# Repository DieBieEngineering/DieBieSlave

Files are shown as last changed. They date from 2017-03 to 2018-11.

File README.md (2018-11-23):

DieBieSlave - Hardware
===
# Introduction
During my work at the University of Twente at the faculty of Biomechanical Engineering I gained interest in EtherCAT and its applications. I learned that many of the projects at this faculty (and other faculties in the field of robotics) desire a custom coupling between a unique sensor and EtherCAT, a coupling that is not always easy to realise with the existing slaves. During my work I helped designing an EtherCAT slave based on the ET1100, this ASIC comes in a BGA package, needs two external ethernet phy's and lots of passive components. The ET1100 is more than capable of coupling all desired applications to EtherCAT however in some applications it's to cumbersome to implement knowing that the LAN9252 can do almost the same and has the ASIC + 2 Phy's intergrated in one QFN package. 

Knowing about the existence of the LAN9252 and hearing the need for a "sensor <--> EtherCAT" interface motivated me to design the project presented here; the DieBieSlave, a universal EtherCAT slave that is able to couple 'any' I2C, SPI, UART, analog, digital or CAN based sensor to EtherCAT. The idea is that the DieBieSlave is universal for any sensor application and has all the 'complex' EtherCAT, power supply and microcontroller hardware on one PCB whilst the only thing that differs per sensor implementation is a cheap and simple daughter board. Every sensor of course needs its unique code to initialise and sample the sensor. 

The DieBieSlave looks like this:
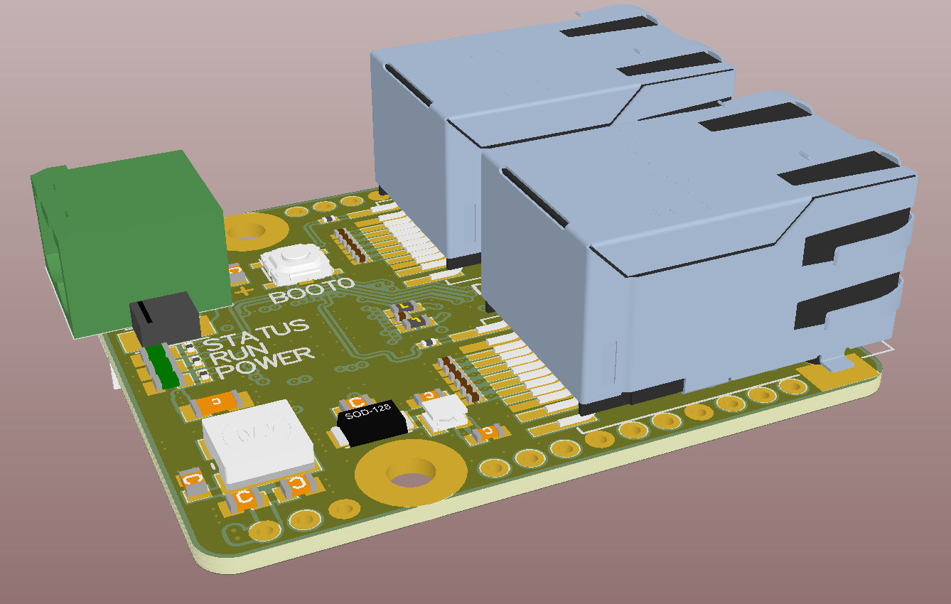
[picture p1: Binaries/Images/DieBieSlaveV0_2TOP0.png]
DieBieSlave V0.2 TopView

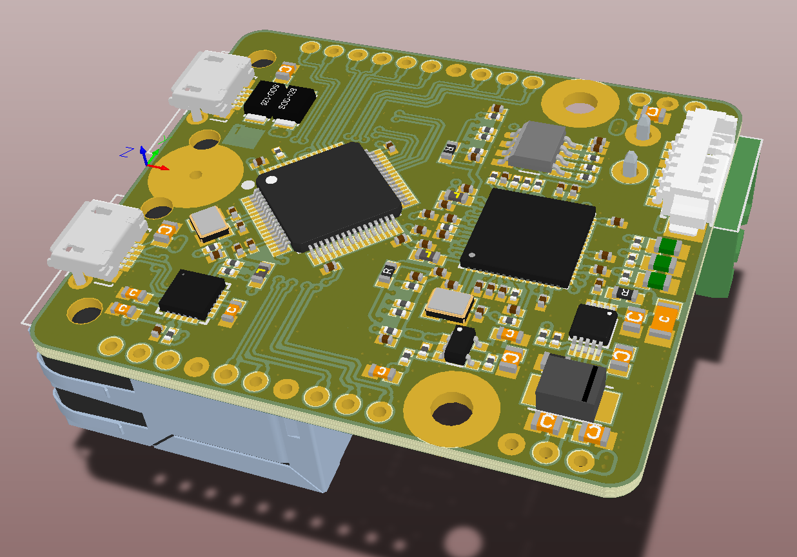
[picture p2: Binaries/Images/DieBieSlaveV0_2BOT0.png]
DieBieSlave V0.2 TopView

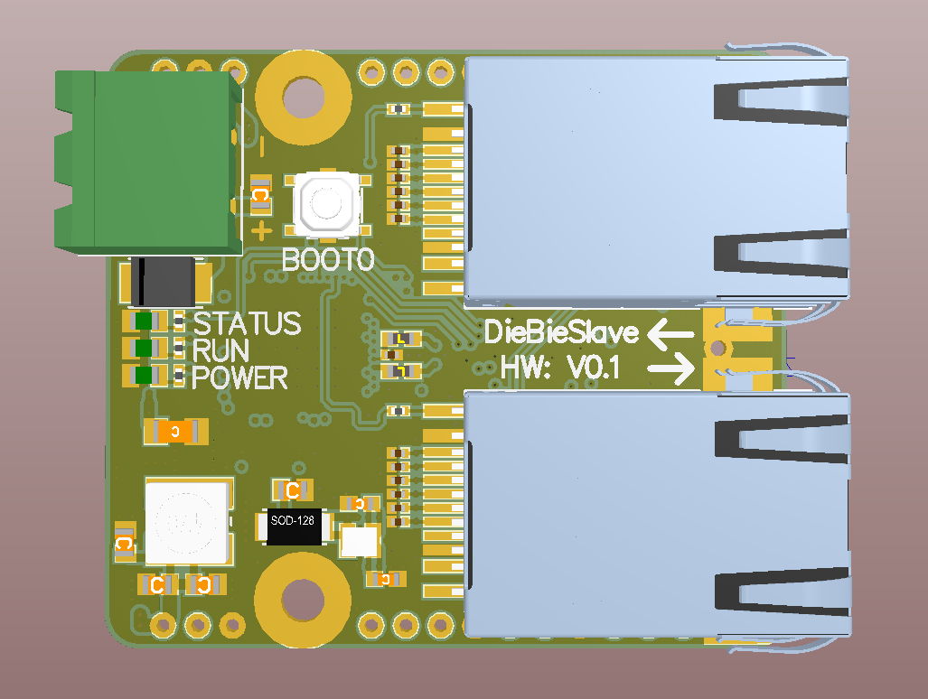
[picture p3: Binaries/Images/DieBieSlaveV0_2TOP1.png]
DieBieSlave V0.2 TopView

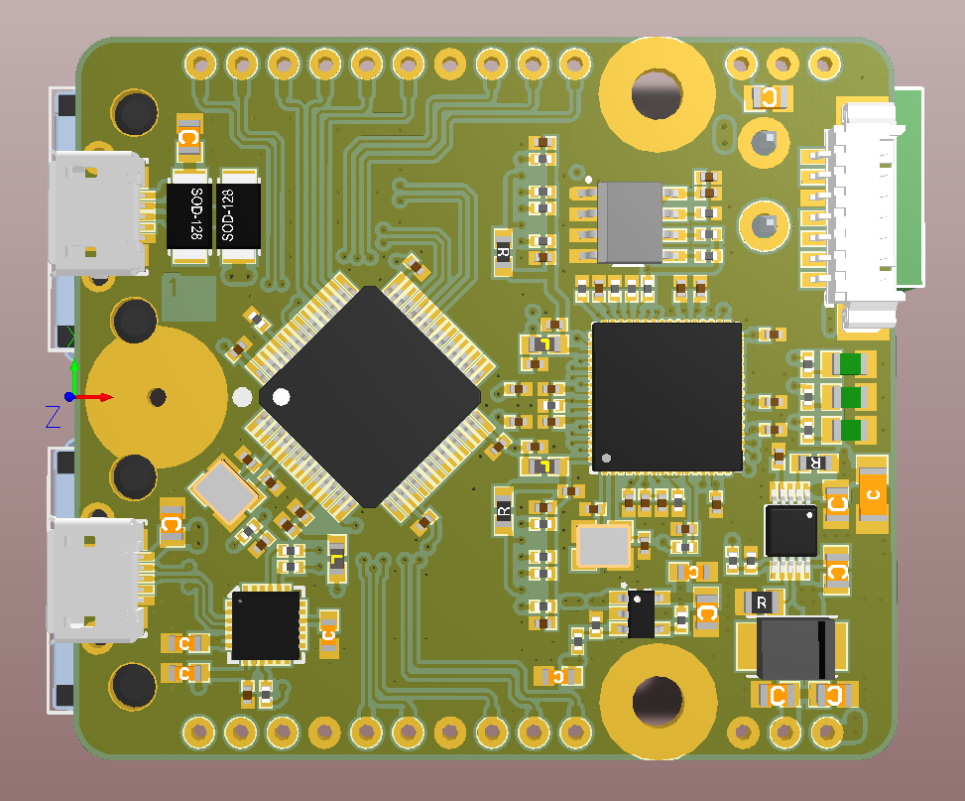
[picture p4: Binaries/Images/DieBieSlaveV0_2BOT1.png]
DieBieSlave V0.2 TopView


On the topside you can see:
* DC (10-30V) power input jack.
* EtherCAT input/output connectors 
* EtherCAT, power and software status LEDs
* BOOT0 HW serial bootloader enable button

On the bottom:
* Micro USB connector that is connected to the HW serial UART1 for general serial communication and HW Bootloader
* Micro USB connector that is connected to the HW USB peripheral of the STM32F303RET6
* 7Pin picoblade debug connector that is connected to the SWD and UART2 peripheral of the STM32F303RET6.

Both sides:
The holes on both edges of the DieBieSlave interface to all exposed (I2C, SPI, UART, analog, digital and CAN) peripherals on the STM32F303RET6 and should be connected to the desired target sensor. Standard 2.54mm headers can be soldered to both sides of the DieBieSlave allowing the use of standard 2.54mm male/female headers to connect standaard prototype board to either the small area on top or the full area on the bottom (realising either a compact or extensive interface). The board connected to the pin on te side that interfaces to a sensor is called a daughter board.

More details can be found in the schematic [here](/Project%20Outputs%20for%20DB10012_UniversalSlave/DB10012_DieBieSlave.PDF).

### Latest hardware release (production files)

* V0.1 Initial hardware
   This version has the following bug:
   * The INT pint of the LAN9252 was incorrectly connected to PC5 (cannot be muxed to INT input when I2C INT input also used) but should have been connected to PB0 (allows INT functionality at all times). This bug is fixxed in V0.2.
   
* V0.2 Fixed version of V0.1 with added functionality (current version)
   This version has some added functionality:
   * The DC-DC power input 10-30V is also routed to the header pins, now the DieBieSlave can be powered by the daughter board if desired.
   
Production data for most recent version can be found [here](Project%20Outputs%20for%20DB10012_UniversalSlave). And the schematic in PDF [here](DB10012_UniversalSlave.PDF).

### Features
The DieBieSlave is designed in such a way that it is easy to manufacture and has a relatively small footprint (by a professional). The implementation of a daughter board is completely up to the user. The DieBieSlave PCB has the following features:

* Power LED on both sides of the PCB.
* EtherCAT RUN LED on both sides of the PCB.
* Sofware status LED on both sides of the PCB connected to pin PB15.
* DC input range of 10-30V (possibly broader but untested) allowing simple implementation in 12V and 24V systems.
* Onboard +5V and +3V3 SMPS power supplies that are exposed to the daughter board header.
* Large powerful microcontroller with DSP and FPU STM32F303RET6 (cortex-M4 512Kbytes flash and 64Kbyte SRAM).
* RJ45 EtherCAT in and output connectors.
* LAN9252 QFN based EtherCAT ASIC.

### Electrical specifications
* DC input power range 10-30V reverse polarisation protected
* The +5V power supply can deliver up to 400mA
* The +3V3 power supply  can deliver up to 200mA

# Realisation
As stated in the introduction the DieBieSlave is a universal EtherCAT slave implementation that will always need a daughter board supplying the DieBieSlave with information that should be put on the BUS. An example DieBieSlave and daughter board implementation is given here:
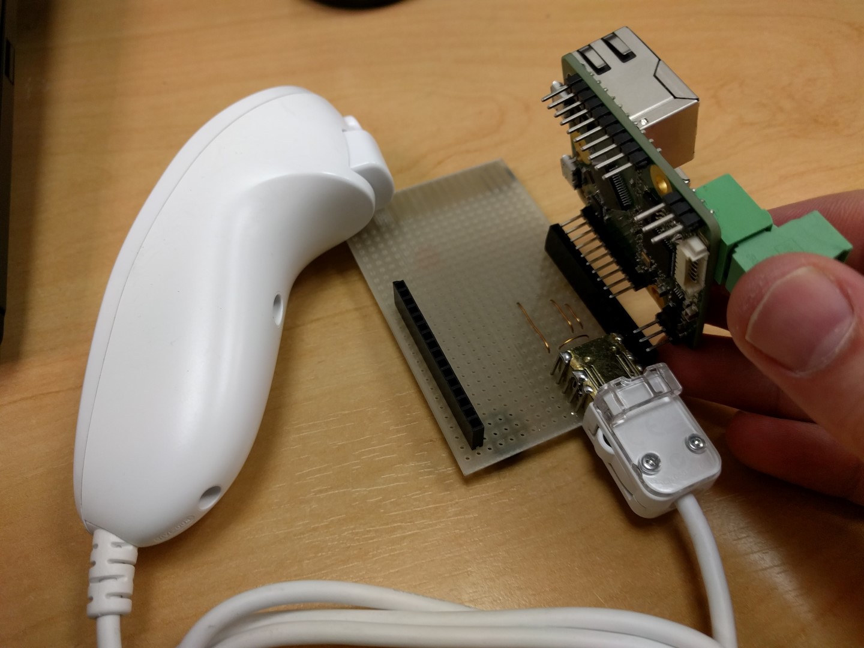
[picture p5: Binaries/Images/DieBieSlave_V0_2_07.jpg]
Daughter board and DieBieSlave separated

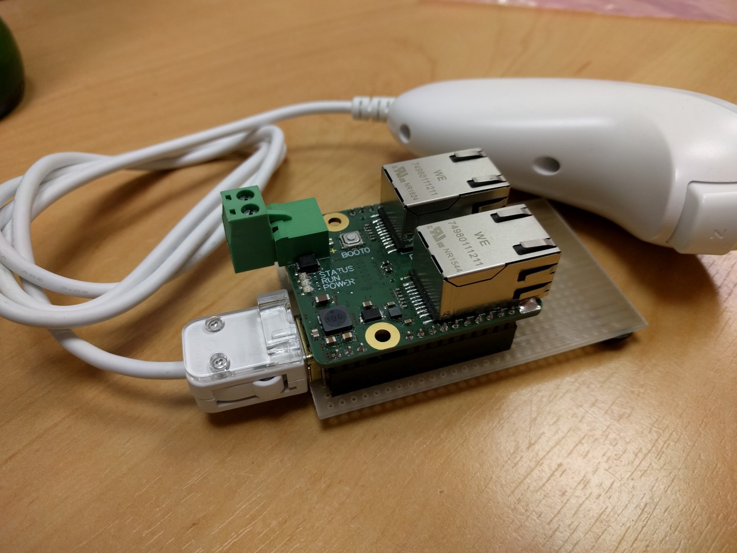
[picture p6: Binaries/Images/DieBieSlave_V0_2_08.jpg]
Daughter board and DieBieSlave connected

As seen the daughter board can be anything from standard perforated prototype board up to a custom designed board carrying the sensor. 

#### LAN9252 vs ET1100
Altrough the LAN9252 seems a perfect replacement for the ET1100 with its two embedded phy's, the QFN package and its low amount of external components it has a big drawback on the software side. Whilst the ET1100 has a transparant interface to its internal RAM over SPI the LAN9252 has not and needs some form of adres translation that prevents large chunks of (PDO) data to be written in a single block, this prevents the use of DMA syncing between uC and LAN9252. The only alternative is rather software labour intensive (the adres translation needs to be done in software) compared to its DMA alternative. This is no deal breaker for sensor acquisition (sensors need very little processor power) but will be a drawback in realtime systems like motor controllers.

#### Used technology
The IC's used with their corresponding functionality:
* STM32F303RET6 -> Main microcontroller.
* LAN9252/ML -> EtherCAT slave controller with build-in phy's.
* M24C16-WMN6P -> EEPROM for LAN9252
* LM25011MY/NOPB -> DC power input to +5V converter.
* LMR10510XMFE/NOPB -> +5V to +3V3 converter.
* 74980111211 -> RJ45 connectors with integrated magnetics.
* CP2104-F03-GM -> USB serial converter for bootloader and general serial communication.

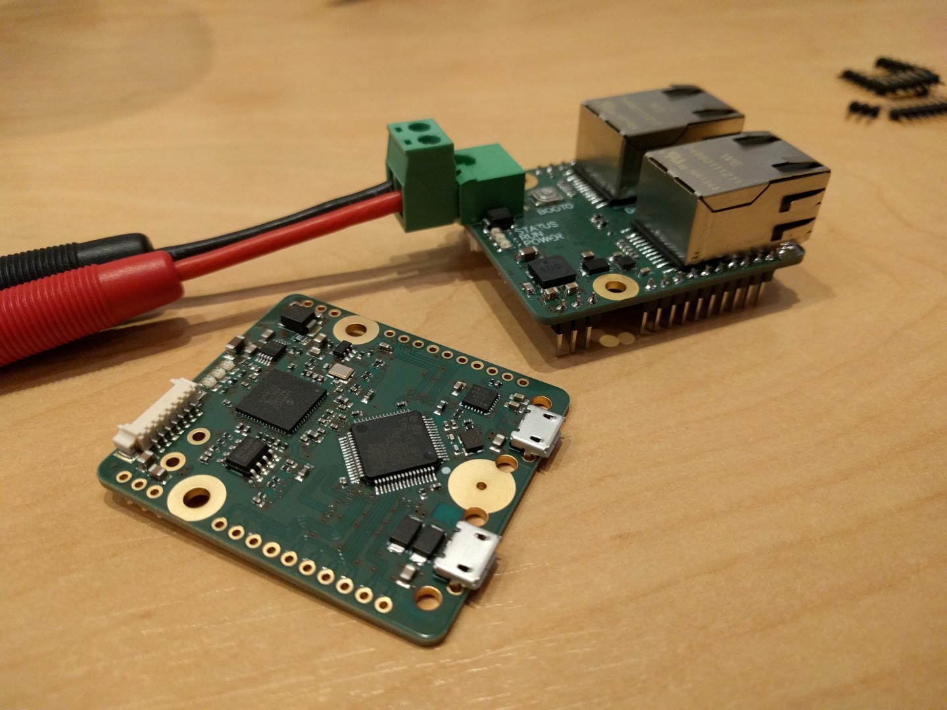
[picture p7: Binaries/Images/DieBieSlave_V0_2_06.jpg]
DieBieSlave V0.2 Dual PCB picture

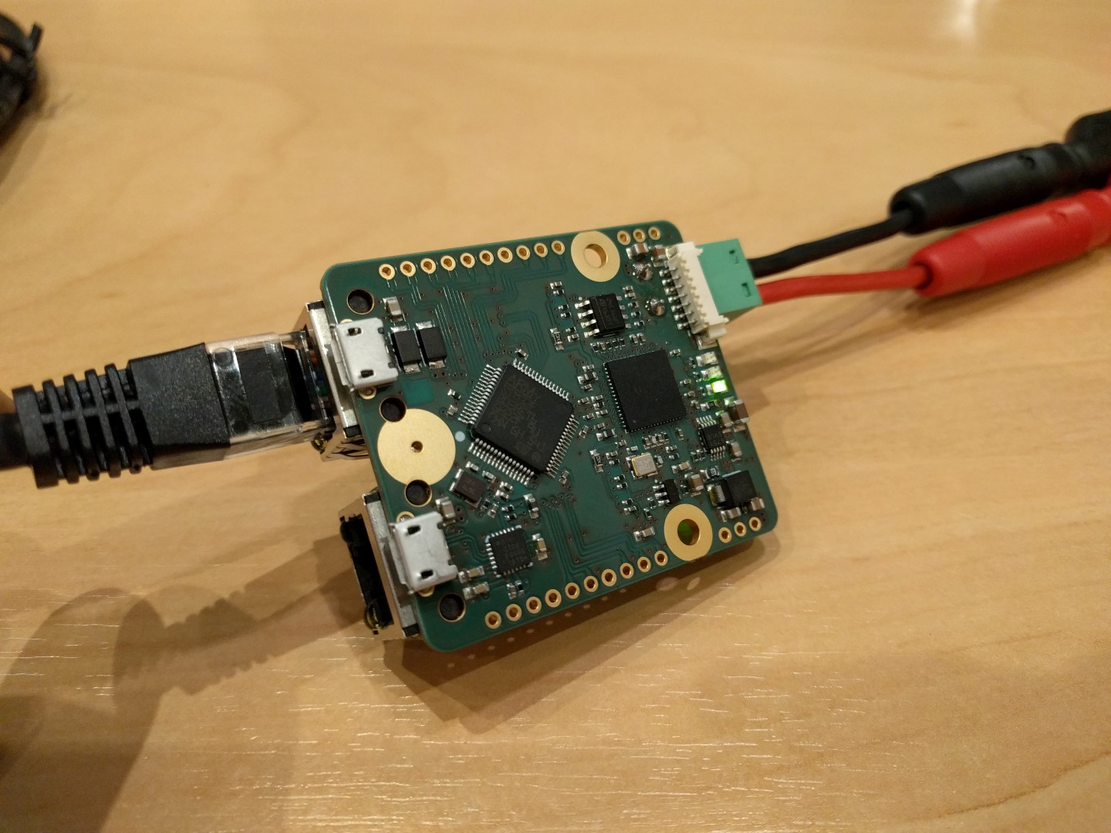
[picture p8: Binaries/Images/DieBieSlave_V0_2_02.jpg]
DieBieSlave V0.2 Bottom overview

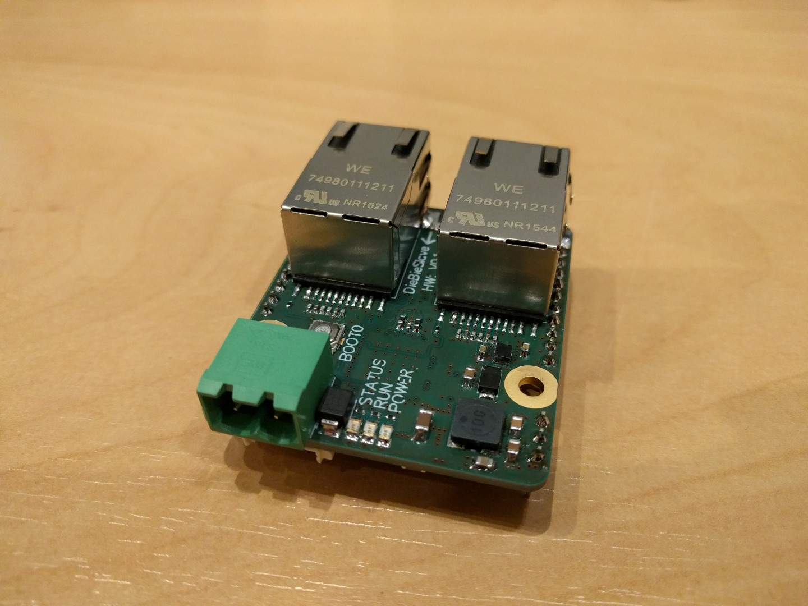
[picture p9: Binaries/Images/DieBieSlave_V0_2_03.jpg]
DieBieSlave V0.2 Top overview

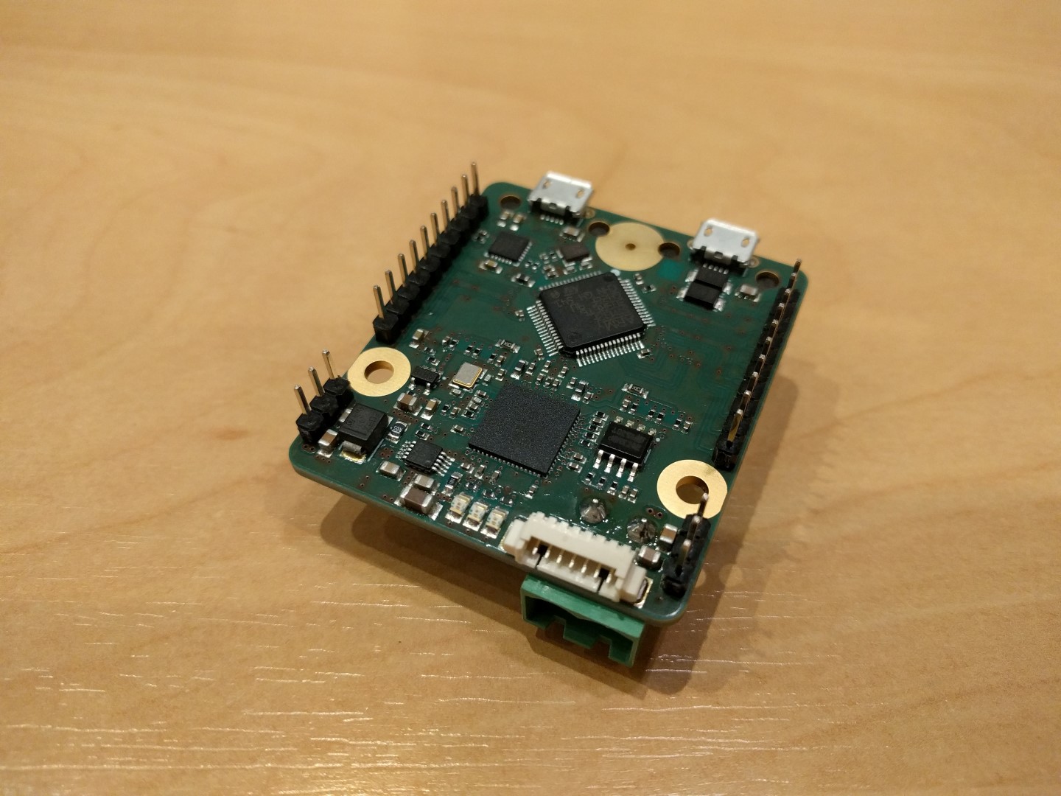
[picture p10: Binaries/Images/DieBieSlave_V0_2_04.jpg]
DieBieSlave V0.2 Bottom component overview

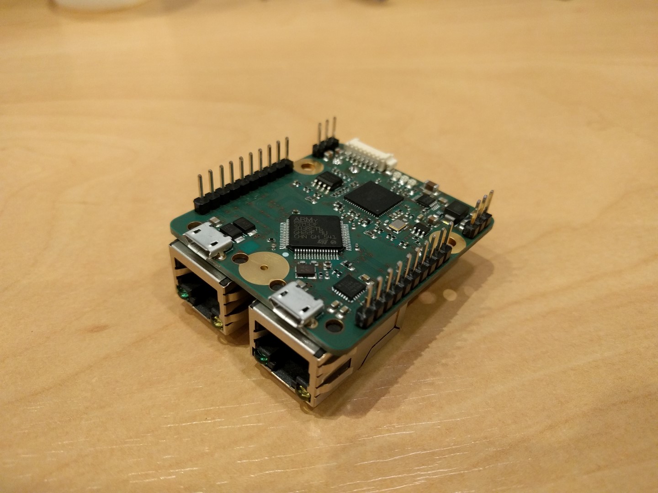
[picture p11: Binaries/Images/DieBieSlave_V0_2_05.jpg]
DieBieSlave V0.2 Bottom component overview


# Example usage
#### MPU9250/NunChuck to EtherCAT
Interfacing a Nun-chuck controller and MPU9250 sensors with EtherCAT:

VIDEO01 (http://www.youtube.com/watch?v=i7gFqLQb0EA)

#### More pictures
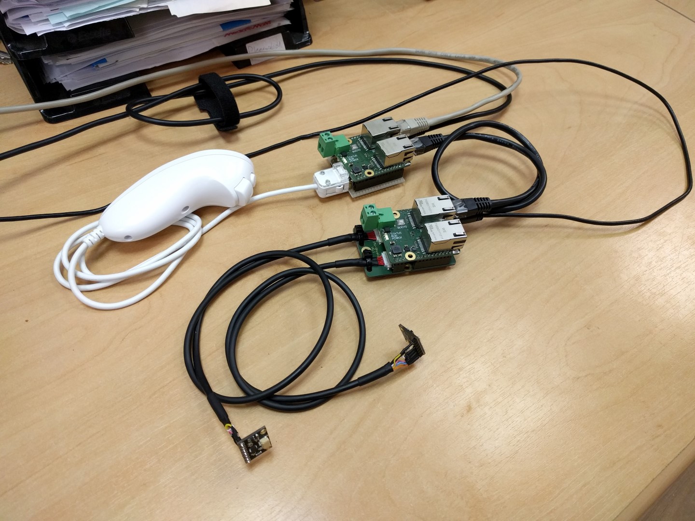
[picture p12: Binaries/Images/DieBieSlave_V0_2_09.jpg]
NunChuck slave and dual MPU9250 slave

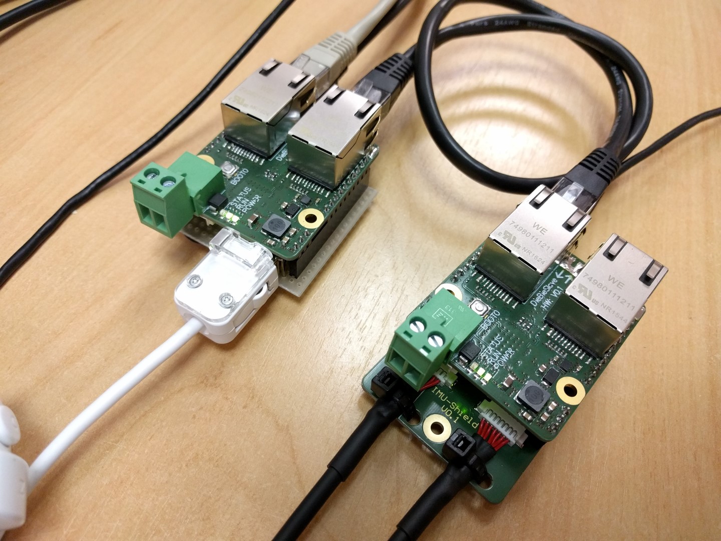
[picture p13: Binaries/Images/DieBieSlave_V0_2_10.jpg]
NunChuck slave and dual MPU9250 slave

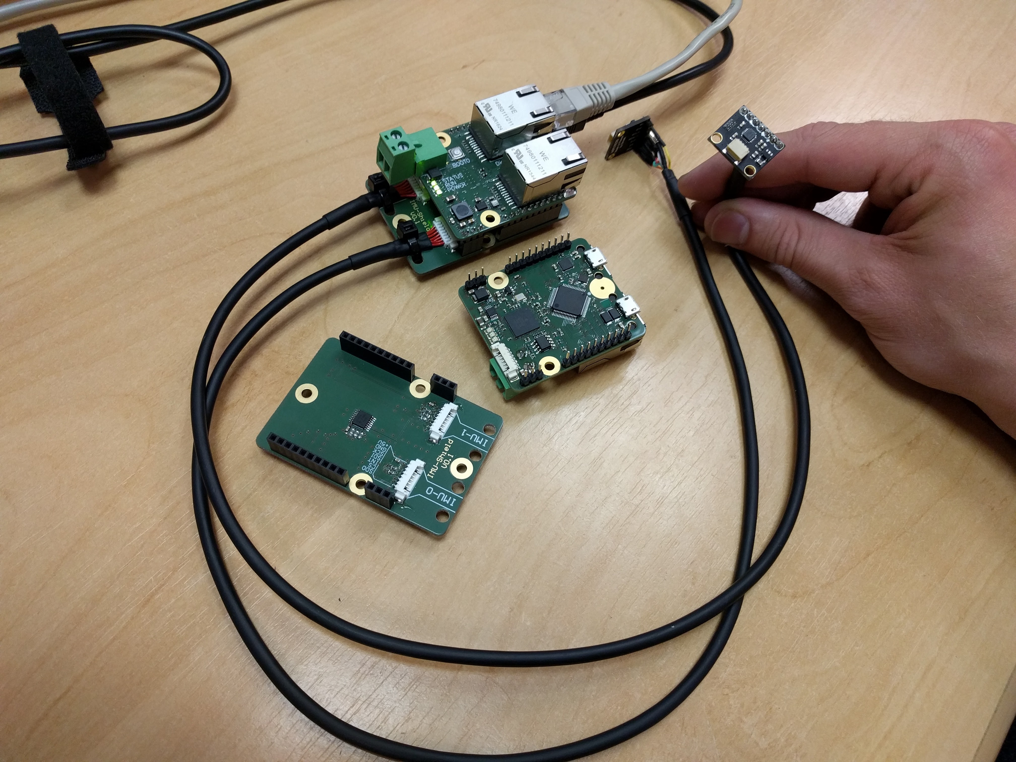
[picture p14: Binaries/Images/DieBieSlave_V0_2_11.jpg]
View of a Shield example

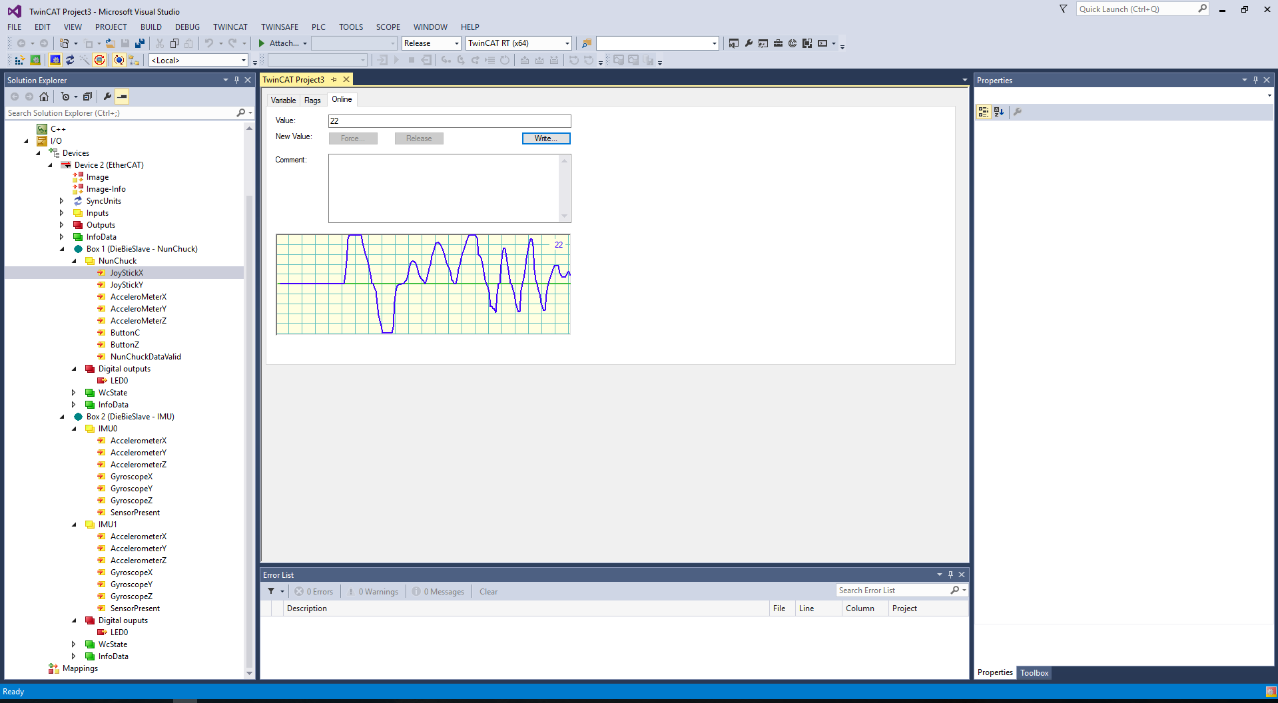
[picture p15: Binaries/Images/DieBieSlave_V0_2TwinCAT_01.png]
TwinCAT screenshot of both slave examples connected

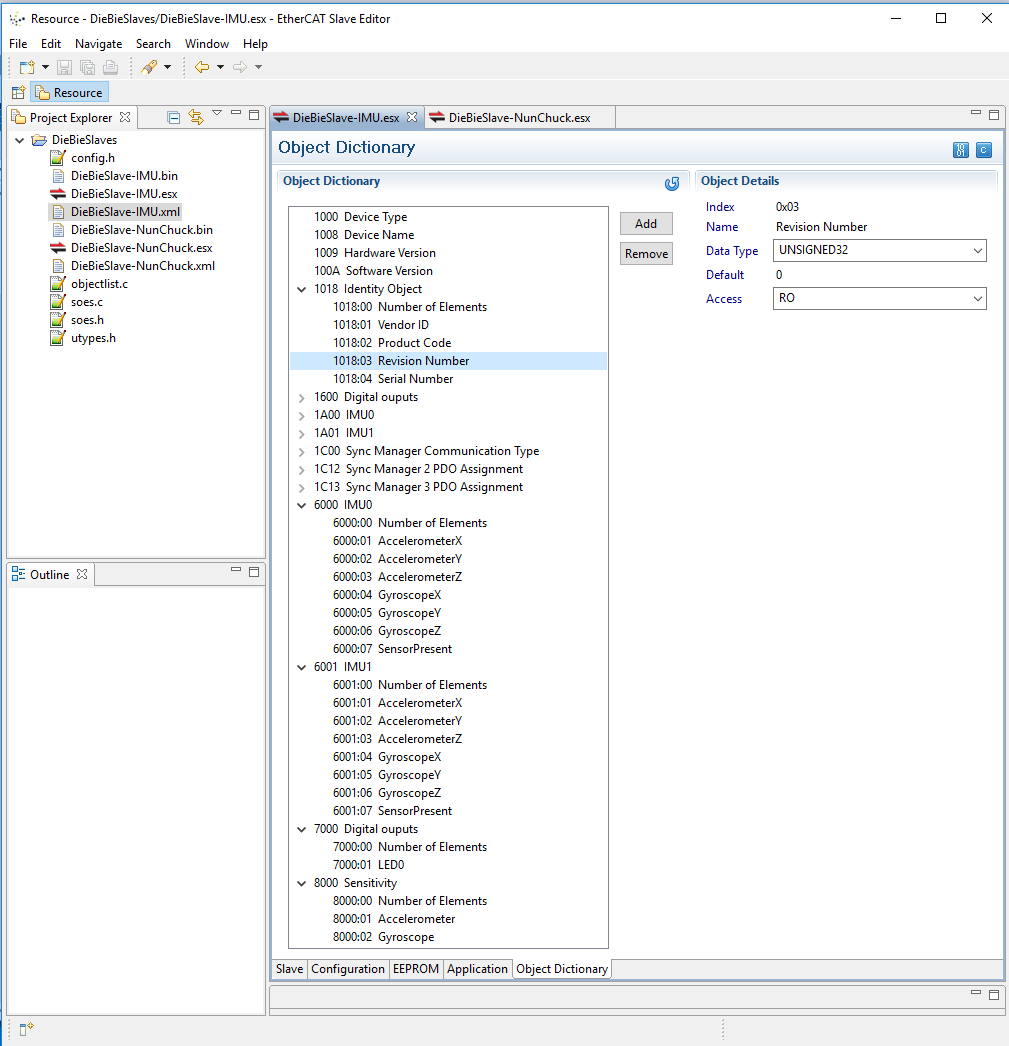
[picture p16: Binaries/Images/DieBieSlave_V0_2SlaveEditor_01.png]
Slave editor view of the SOES configuration


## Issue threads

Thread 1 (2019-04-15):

BOM and layer count

thomasfla, 2019-04-15:
Hi, thanks for this board, I think it will be very usefully for many project!

I'm considering building a couple of boards..
Do you have a BOM ready for the non-Altium users?

Also, looking at the gerber, it looks like it's a 6 layers board. Is it right? Do we really need 6 layers for this project or do you think it's doable on 4 layer with similar ? (or even 2?)

Best,
T.

DieBieEngineering, 2019-04-15:
Hi Thomas!

Thanks for your interest in the project. You can see all data with the free
Altium viewer license. The production data should be available in the repo
as well, either in releases or in the project output folder.

With this small size I am afraid that 6 layer is your only option.

Thanks ,
Danny

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

Closed 2019-06-15.

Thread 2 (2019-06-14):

Code Source

khaledlim, 2019-06-14:
If you can share your code source.I'm studying on a similar project
Thank you

DieBieEngineering, 2019-06-14:
https://github.com/DieBieEngineering/DieBieMS-Firmware

khaledlim, 2019-06-14:
Thank you so much.
if i have any question can i ask you ?

On Fri, Jun 14, 2019 at 10:57 PM Danny Bokma <notifications@github.com>
wrote:

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

DieBieEngineering, 2019-06-14:
Of course!

khaledlim, 2019-06-15:
I worked a conception of  a card that contains :

-STM32f407VGT6 microcontroller.
-Ethercat Slave controller LAN9252 like you connected with SPI1 and an
EEPROM 2Mbit with I2C.
-USB 2.0 FS .
-USB 2.0 HS with external PHY USB3300
-Connector VGA.
-Connector SWD

And i'm disable to program it in Keil V5 , I already did the configuration
of pins in CubeMX.

And why and how should i use TwinCAT software

Thanks

On Sat, Jun 15, 2019 at 12:48 AM Danny Bokma <notifications@github.com>
wrote:

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

DieBieEngineering, 2019-06-15:
That almost looks like a computer, what are you trying to build?

You use Twincat as for example the master controller.

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

khaledlim, 2019-06-16:
I want to build a Card of interfacing of a 6 axis Robot for Control
Automatisation using EtherCAT Fieldbus.
Which programme and libraries should I use for communication SPI1 between
the microcontroller and the LAN9252 ?

On Sat, Jun 15, 2019 at 3:37 PM Danny Bokma <notifications@github.com>
wrote:

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

Closed 2019-06-14.

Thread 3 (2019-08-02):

Placement of the electronic components

FCam1, 2019-08-02:
Hi,
Thanks a lot for this design !
I am building a DieBieSlave board and I encounter difficulties to know the implantation of each components.
I tried with Altium and Cadence to extract the names (L8,C1...) but I can't isolate the layer "name" for each side, it seems the names are on the same layer.
For the instant I wrote the name of each components one by one on a photo of the board but is fastidious and source of errors.

How did you do for mounting your board? Do you have the implantation scheme?

DieBieEngineering, 2019-08-05:
You can download a free Altium viewer version which allows you to see the
board in Altium. This is probably the best and easiest solution.

On Fri, Aug 2, 2019, 11:04 Florenc Caminade <notifications@github.com>
wrote:

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

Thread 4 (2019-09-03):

LAN9252 configuration

FCam1, 2019-09-03:
Hi,
We have built a board and it seems to work ! For the moment I did some tests with the  [SOEM library](https://github.com/OpenEtherCATsociety/SOEM) and the device is recognized as a slave.

As I understand the LAN9252 have to be configured through ethercat, for that you give an [DieBieSlave-IMU.esx](https://github.com/DieBieEngineering/DieBieSlave-Firmware-IMU/tree/master/ESIEtherCAT) and it has to be opened with [ethercat-SDK](https://rt-labs.com/refman/ethercat-sdk/slaveeditor.php) in order to generate a binary. This binary can be sent to the LAN9252 with this [eepromtool](https://github.com/OpenEtherCATsociety/SOEM/tree/master/test/linux/eepromtool), for example. Am I right ?
Another point : I can't generate the binary file in ethercat-SDK with the free licence. Did you buy the licence?

Thanks

DieBieEngineering, 2019-09-03:
Dear Florenc,

Thanks for your email! Sounds good!

Yes I use twincat and the xml file to configure/write the eeprom data to
the slave. The xml and esc are made with the tool provided by rt-labs, back
then the tool was free and allowed for the generation of this section and
description. I am not up to speed with the current status and whether it is
still free.......

Op di 3 sep. 2019 om 10:33 schreef Florenc Caminade <
notifications@github.com>:

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

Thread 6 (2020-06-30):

Wrong routing on decoupling capacitors

SavKok, 2020-06-30:
Hello,

There are some routing faults on decoupling capacitors. The power line track should go first throught the capacitor and the to the VDD pin.

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

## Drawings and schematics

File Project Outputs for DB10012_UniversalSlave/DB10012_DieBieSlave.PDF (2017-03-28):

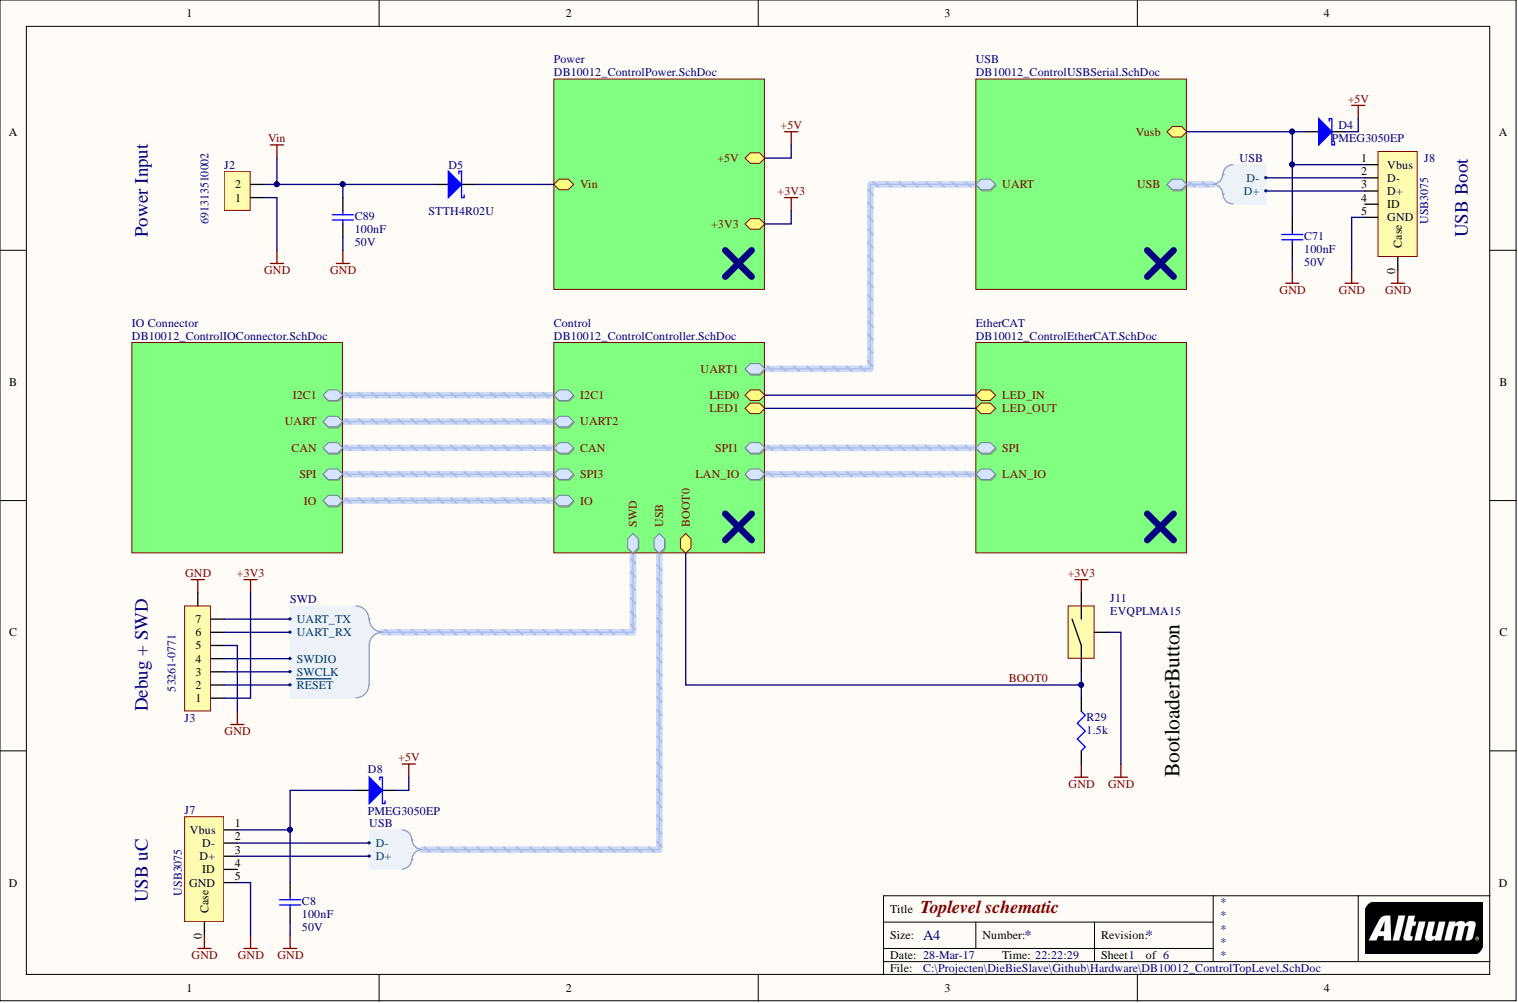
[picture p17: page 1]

Size: A | N umber: | Rev s
Date: 8-Mar-1 T ime: : | | Sheet f

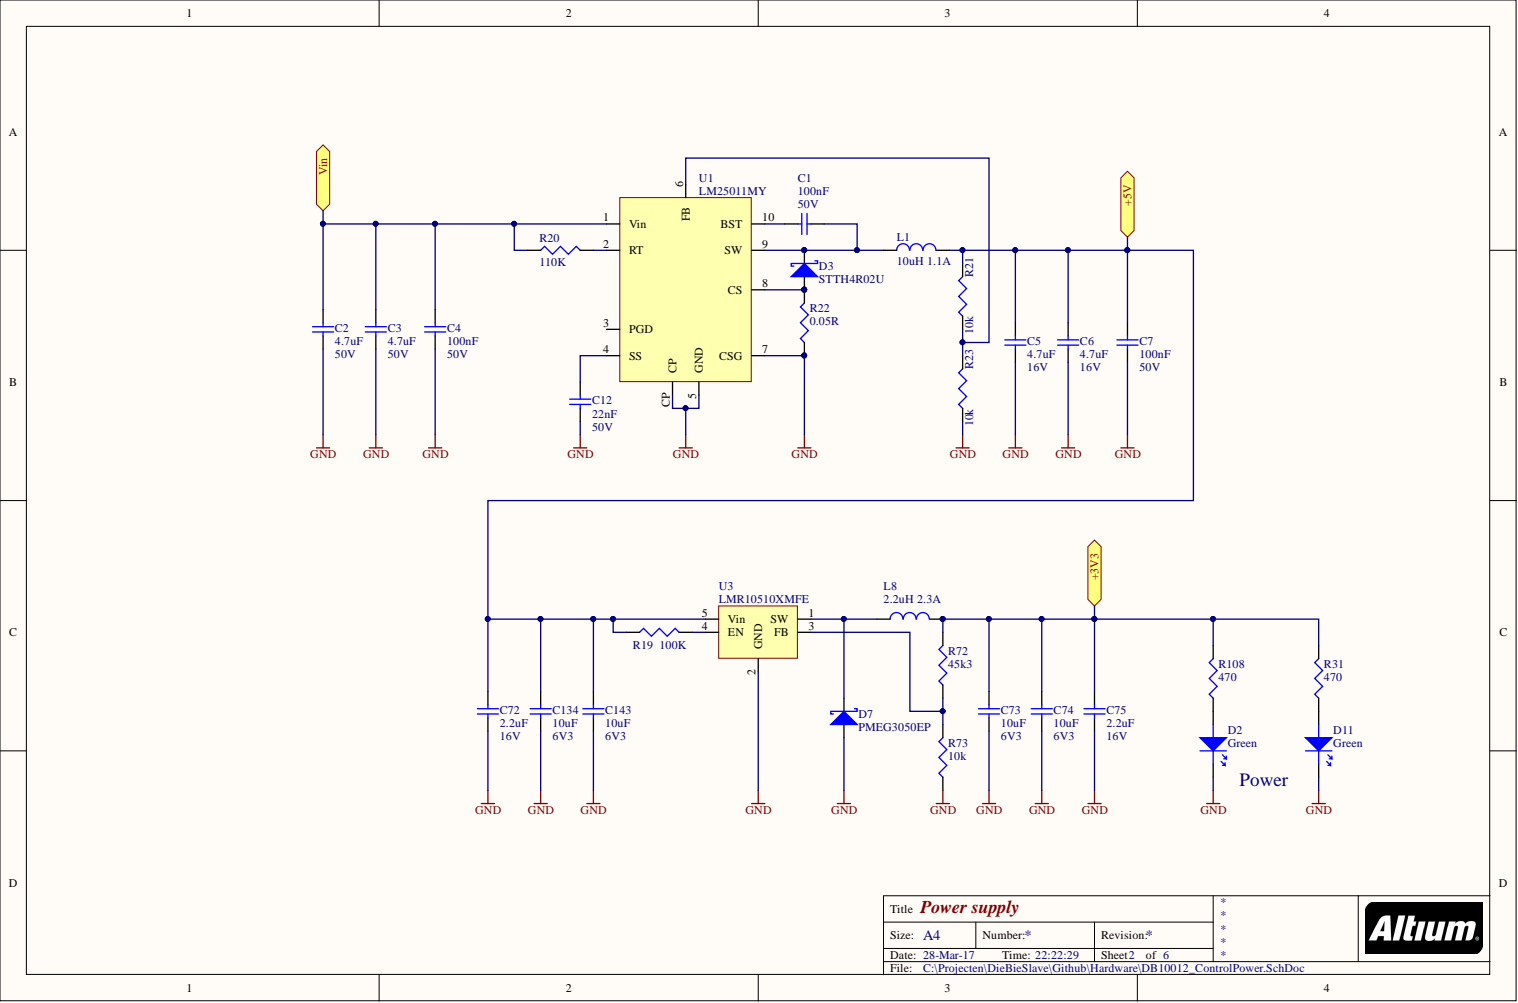
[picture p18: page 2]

Vin 1

Title Power supply | * *

Size: A4 | Number: * | Revision: *
28-Mar-17 Time: 22:22:29 | | Sheet of

C:\Projecten\DieBieSlave\Github\Hardware\DB10012_ControlPower.SchDoc

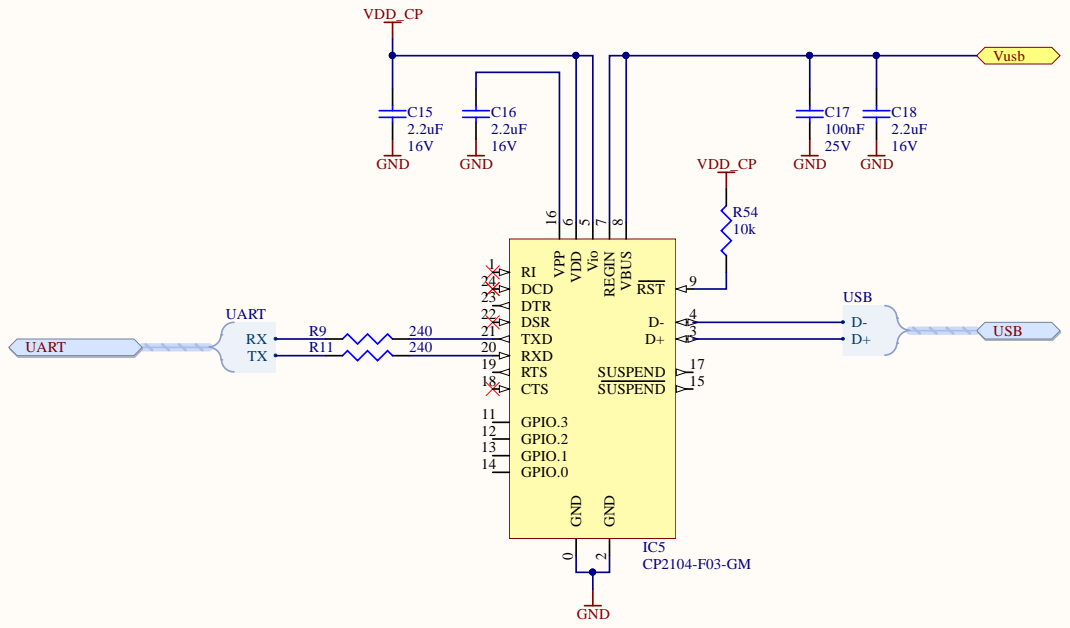
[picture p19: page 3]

C:\Projecten\DieBieSlave\Github\Hardware\DB10012_ControlUSBSerial.SchDoc

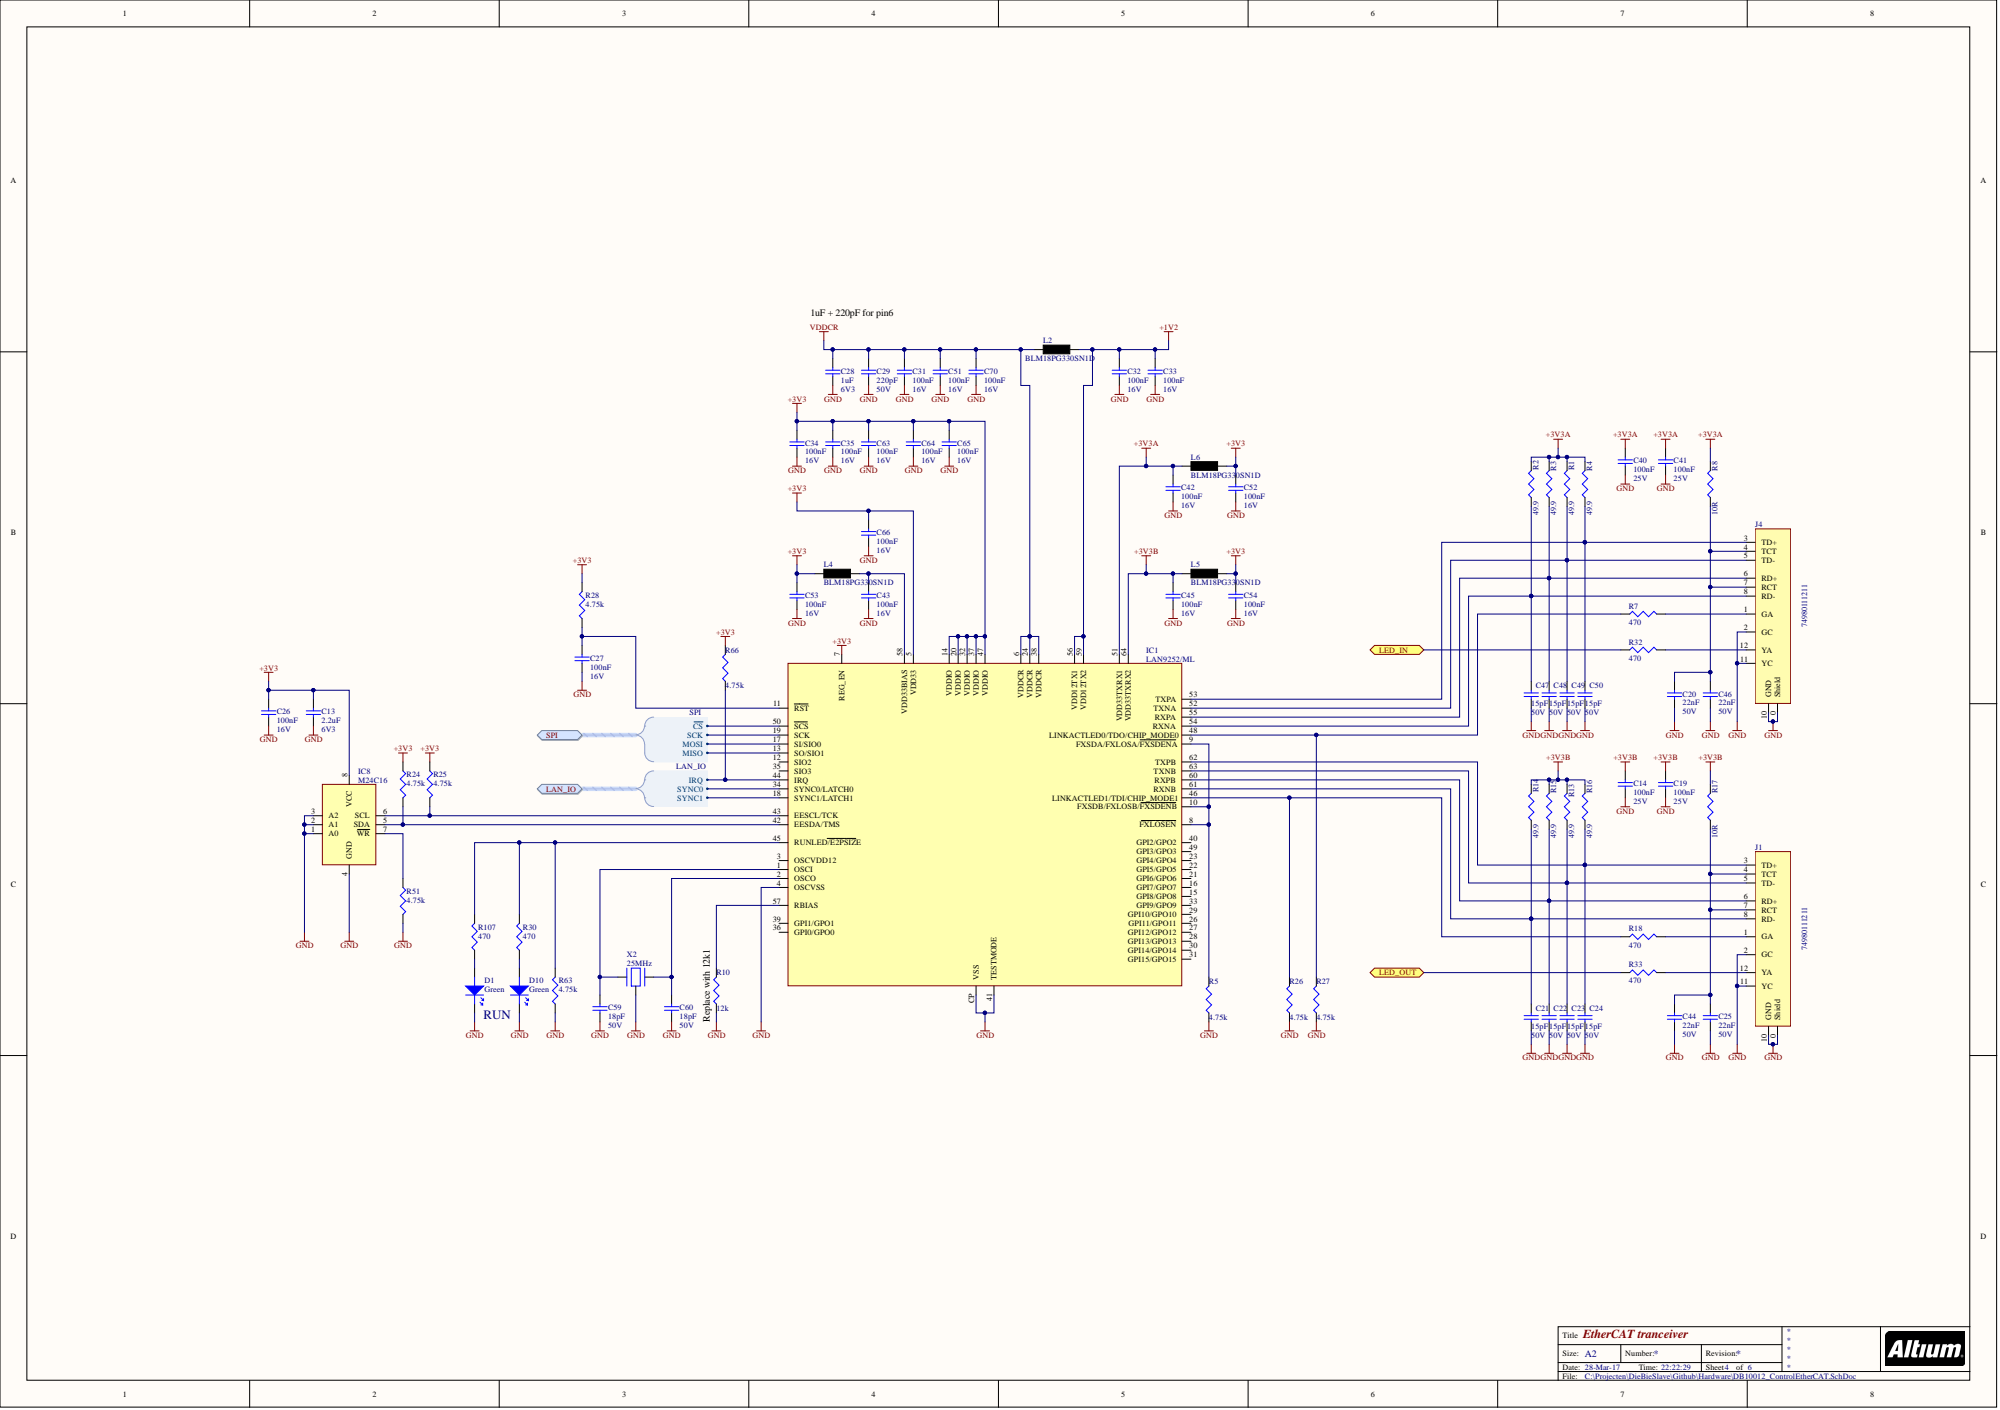
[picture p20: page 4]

6 0
6 1

4 6
1 0 | | G

2 | 5 | 4 2
1 | 7 | | 4 0 9 3 2

5 3 | | | | | 6
9 6 | | | | | 7

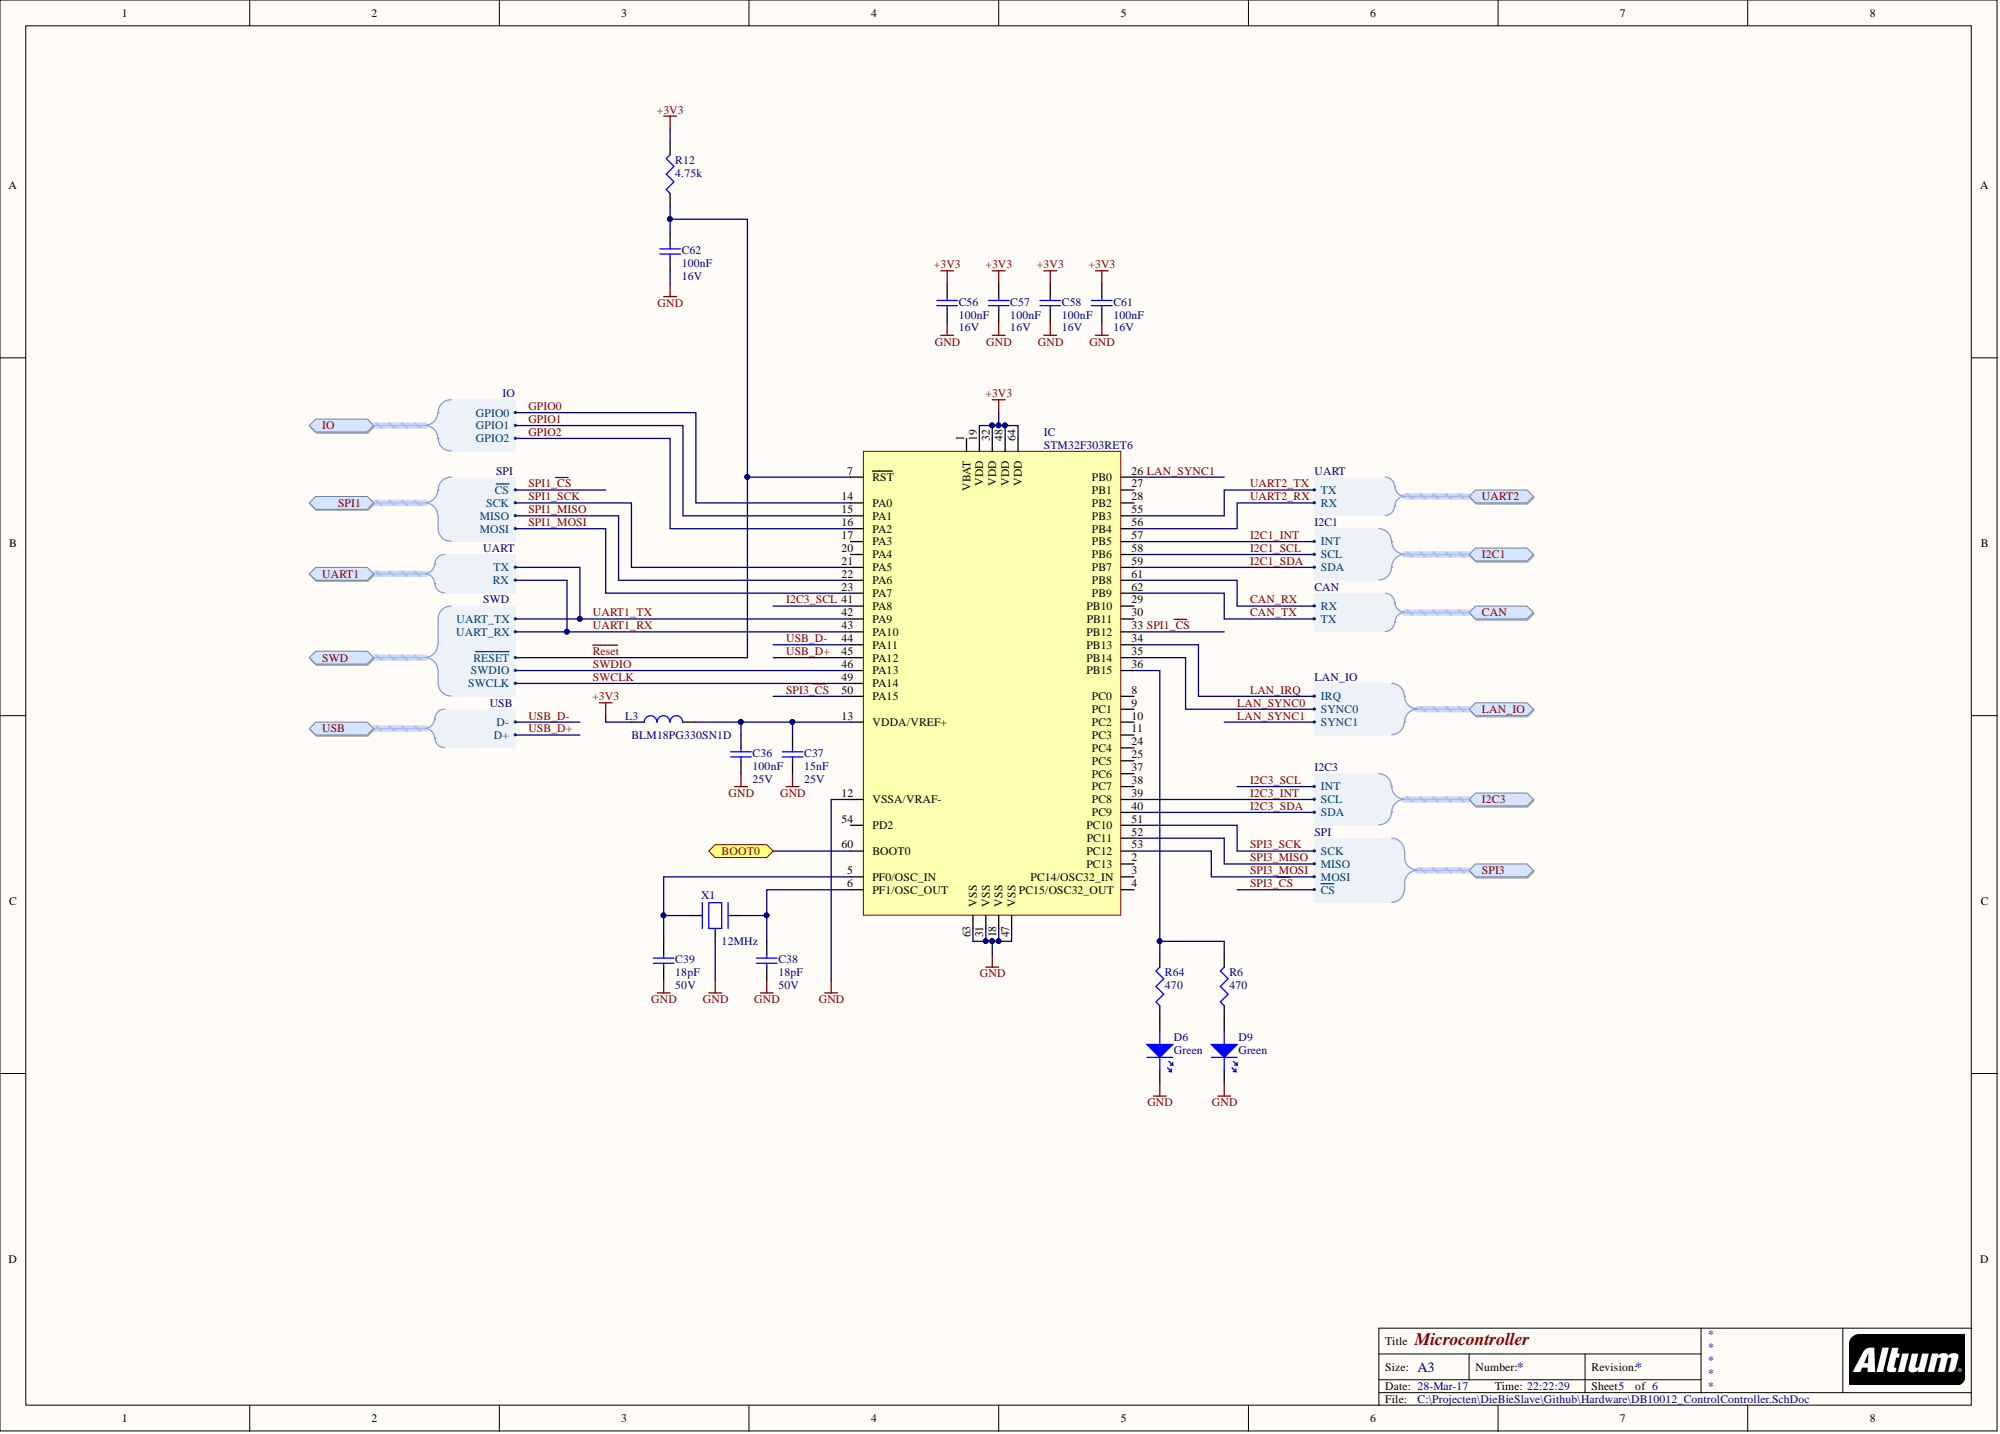
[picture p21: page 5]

GPIO 1
GPIO 2

SPI1 _CS

SPI1 _MISO | | | | 5 5
SPI1 _MOSI | | | | 5 6

2 | 3 | | 6 2

I2C3 _SCL 4 1 _ T X 4 | 1 2 | | 2 9 CA N _RX

USB_ D -4 USB_ D + 4 | | | 4 5

3 5
3 6

9 | L A N _SY NC0
1 0 1 4 5 7 8 9

5 3 | SPI3 _SCK
2 | SPI3 _MISO
3 | SPI3 _MOSI

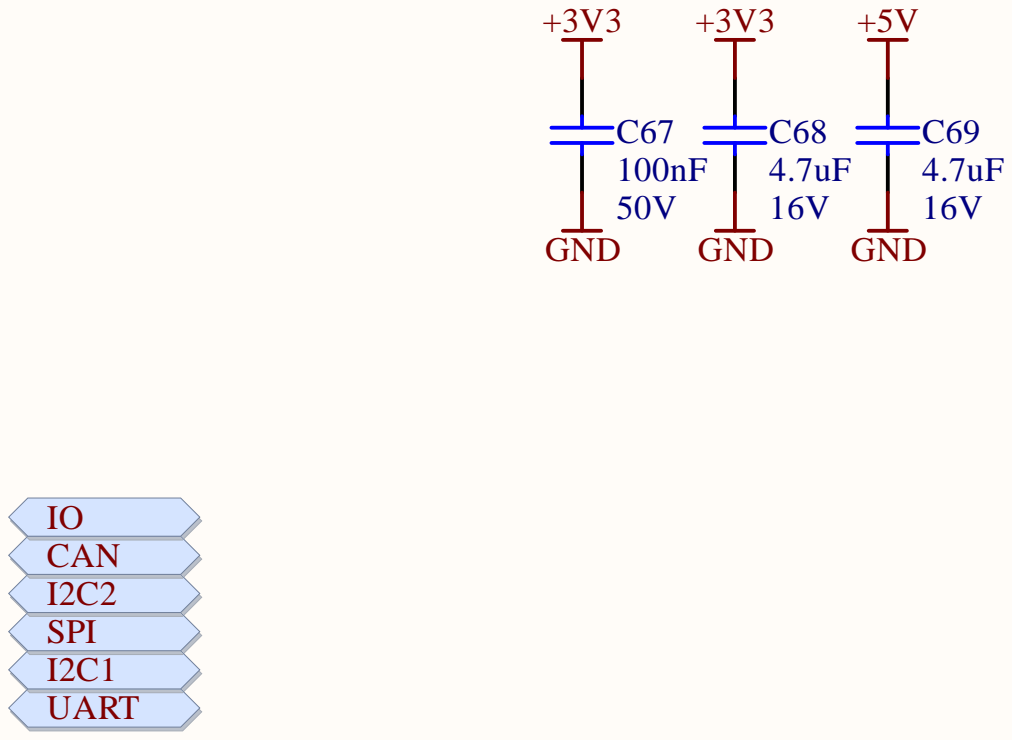
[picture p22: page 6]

C:\Projecten\DieBieSlave\Github\Hardware\DB10012_ControlIOConnector.SchDoc

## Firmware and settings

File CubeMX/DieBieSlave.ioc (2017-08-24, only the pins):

Mcu.UserName=STM32F303RETx
PA0.GPIO_Label=GPIO0
PA0.Signal=GPIO_Output
PA1.GPIO_Label=GPIO1
PA1.Signal=GPIO_Output
PA10.Signal=USART1_RX
PA11.Signal=USB_DM
PA12.Signal=USB_DP
PA13.Signal=SYS_JTMS-SWDIO
PA14.Signal=SYS_JTCK-SWCLK
PA15.GPIO_Label=SPI3_CS
PA15.Signal=GPIO_Output
PA2.GPIO_Label=GPIO2
PA2.Signal=GPIO_Output
PA5.GPIO_Label=LAN_SCK
PA5.Signal=SPI1_SCK
PA6.GPIO_Label=LAN_MISO
PA6.Signal=SPI1_MISO
PA7.GPIO_Label=LAN_MOSI
PA7.Signal=SPI1_MOSI
PA8.Signal=I2C3_SCL
PA9.Signal=USART1_TX
PB0.GPIO_Label=LAN_SYNC1
PB0.Signal=GPIO_Input
PB12.GPIO_Label=LAN_CS
PB12.Signal=GPIO_Output
PB13.GPIO_Label=LAN_IRQ
PB13.Signal=GPXTI13
PB14.GPIO_Label=LAN_SYNC0
PB14.Signal=GPXTI14
PB15.GPIO_Label=LED_DEBUG
PB15.Signal=GPIO_Output
PB3.Signal=USART2_TX
PB4.Signal=USART2_RX
PB5.GPIO_Label=I2C1_INT
PB5.Signal=GPIO_Input
PB6.Signal=I2C1_SCL
PB7.Signal=I2C1_SDA
PB8.Signal=CAN_RX
PB9.Signal=CAN_TX
PC10.Signal=SPI3_SCK
PC11.Signal=SPI3_MISO
PC12.Signal=SPI3_MOSI
PC8.GPIO_Label=I2C3_INT
PC8.Signal=GPIO_Input
PC9.Signal=I2C3_SDA
PF0-OSC_IN.Signal=RCC_OSC_IN
PF1-OSC_OUT.Signal=RCC_OSC_OUT

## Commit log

2017-03-23 Initial commit.
    [DB10012_ControlController.SchDoc, DB10012_ControlEtherCAT.SchDoc, DB10012_ControlIOConnector.SchDoc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]
2017-03-26 Fixed name error.
    [DB10012_UniversalSlave.DRL, DB10012_UniversalSlave.GBL, DB10012_UniversalSlave.GBO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]
2017-03-26 More file naming fixing.
    [DB10012_UniversalSlave.PrjPcb]
2017-03-28 Changed schematic and changed its location.
    [DB10012_ControlEtherCAT.SchDoc, DB10012_ControlIOConnector.SchDoc, DB10012_ControlPower.SchDoc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]
2017-08-24 Minor schematic changes.
    [DB10012_ControlController.SchDoc, DB10012_ControlTopLevel.SchDoc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]
2017-12-14 Latest design sync.
    [DB10012_ControlController.SchDoc]
